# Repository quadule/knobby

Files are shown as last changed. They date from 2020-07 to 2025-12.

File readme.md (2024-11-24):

# Knobby: a little remote for Spotify and more





## Knobby is the remote control made for discovering music and rediscovering your own collection; _your one-click cure for musical boredom_.

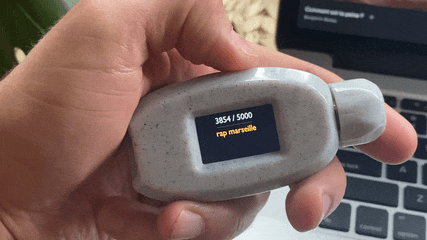
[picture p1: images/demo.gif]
example of playing a random genre with a Knobby


### One knob controls your musical universe

* Spin and explore **6,000+** microgenre and country playlists from [everynoise.com](https://everynoise.com)
* Or hold the knob to randomize — **put all of Spotify on shuffle!**
* Enjoy fast access to your own playlists and liked songs
* See what's playing and control playback on any Spotify Connect device

<br clear="all">
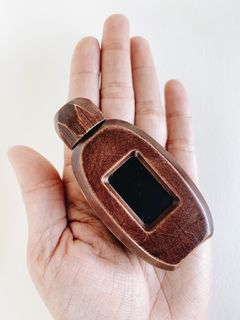
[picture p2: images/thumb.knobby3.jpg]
knobby with wood finish in hand


### Untether music from your phone

Always ready, free from distractions, and designed to be shared: Knobby is the perfect partner to any smart speaker. Show off your meticulously curated collection in your home, or pass it around a party and let your guests take control.

<br clear="all">
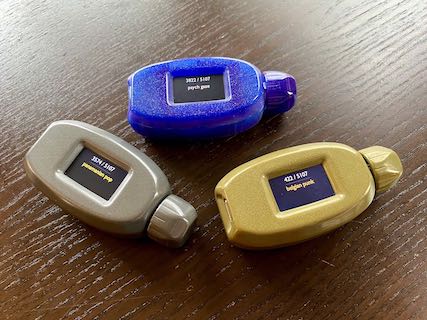
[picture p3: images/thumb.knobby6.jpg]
three knobby remotes


### Make it yours(elf)

Knobby’s minimal design is easy to build and customize, with open source firmware based on the Arduino framework. The 3D printed enclosure is designed around a common ESP32 development board and a single rotary encoder. You can [buy one from me](https://www.tindie.com/products/milowinningham/knobby-a-little-remote-for-spotify-and-more/) to support this project, or [build one yourself](#build-your-own).


<br clear="all">

### See it in action

https://user-images.githubusercontent.com/15299/221440478-d7a543d5-4e82-4146-b03c-dc35ea191b35.mp4

### Read more

- [**Hackaday**: Small Spotify Remote Broadens Musical Horizons](https://hackaday.com/2020/10/21/small-spotify-remote-broadens-musical-horizons/)
- [**Hackster**: Knobby Is a Unique Handheld Remote That Controls Spotify Connect Devices](https://www.hackster.io/news/knobby-is-a-unique-handheld-remote-that-controls-spotify-connect-devices-e3428e100ab6)
- [**Tindie Blog**: Knobby! Explore Music in a New Way](https://blog.tindie.com/2022/11/knobby-explore-music-in-a-new-way/)

## Usage

* Turn the knob to navigate between menu items.
* Click the knob to select or play something.
* Push in and rotate the knob to switch menus.
* Hold the knob for couple seconds for a random genre, country, or playlist from the last open menu.
  - Keep holding the knob until the progress bar reaches the end to play immediately.
  - Release the knob before the progress bar reaches the end to keep browsing.
* When browsing genres, double click the knob to switch between the default alphabetical order and sorting by suffix.
* When playing something, double click the knob to skip to the next track.

### Requirements

* **Spotify Premium** is required — Knobby will not function properly on a free account.
* An always-on playback Spotify Connect device is highly recommended. Knobby can control any Spotify app or device, but a smart speaker or home audio system usually works best. If using a mobile app or some devices such as Chromecast, playback must be started before it can be controlled though Knobby.

## Build your own

### Get the parts

* [LilyGO TTGO T-Display ESP32 board with ST7789 240x135 display](https://www.aliexpress.com/item/33048962331.html)
* [Bourns PEC11R-4215F-S0024 rotary encoder](https://www.mouser.com/ProductDetail/Bourns/PEC11R-4215F-S0024?qs=Zq5ylnUbLm5lAqmKF80wzQ%3D%3D)
* [MakerFocus 1100mAh LiPo battery](https://www.makerfocus.com/products/makerfocus-3-7v-1100mah-lithium-rechargeable-battery-1s-3c-lipo-battery-with-protection-board-pack-of-4)
* [3D printed case and knob](https://www.printables.com/model/156363)

Or, install the firmware on another supported ESP32 development board:

* [LilyGO T-Embed](https://www.lilygo.cc/products/t-embed)

### Wire it up

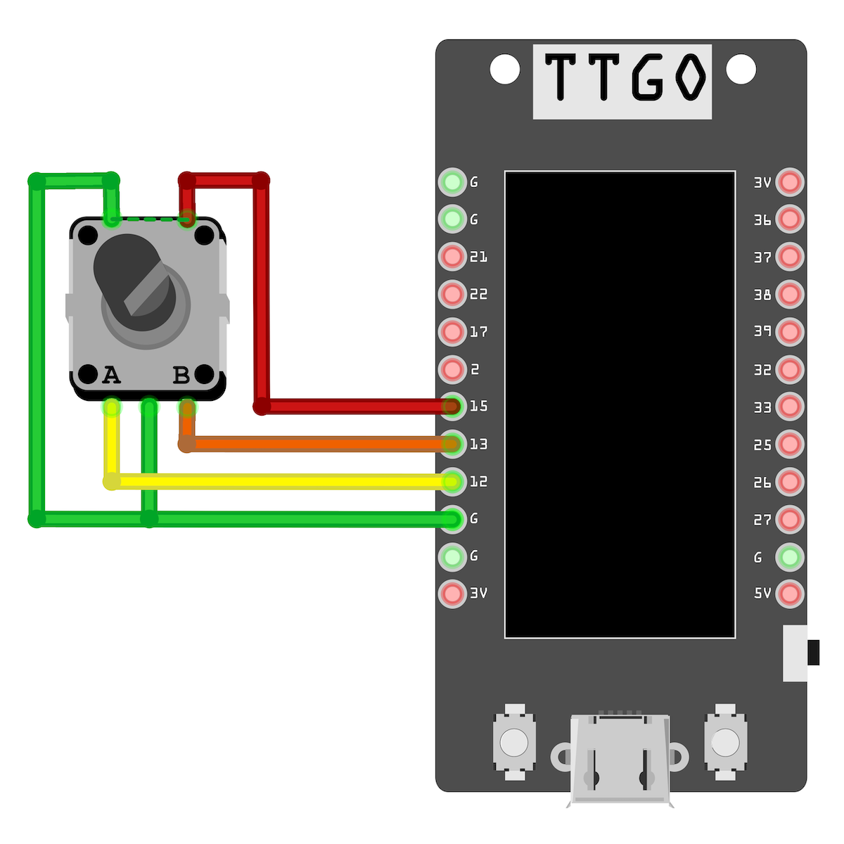
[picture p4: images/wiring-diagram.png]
wiring diagram of rotary encoder with t-display board


1. Connect the rotary encoder A and B pins to GPIO pins 12 and 13.
2. Connect one pole of the switch to GPIO pin 15.
3. Connect other pole of the switch and the encoder’s remaining middle pin to ground.

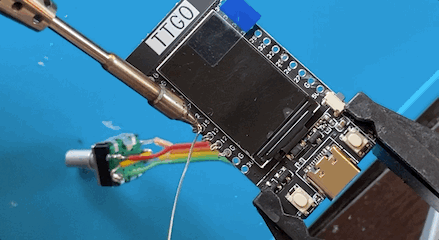
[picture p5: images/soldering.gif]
soldering rotary encoder’s wires to the circuit board


### Install the firmware
#### ➡️ [setup.knobby.net](https://setup.knobby.net)

The [Knobby setup tool](https://setup.knobby.net) can flash the latest firmware and configure wifi credentials over USB (requires Google Chrome or Microsoft Edge for Web Serial API support).

Alternatively, you can download [the latest release](https://github.com/quadule/knobby/releases/latest) and flash it yourself. You will need to have Python and [esptool.py](https://github.com/espressif/esptool) installed. With the USB cable connected, run the flash script in the directory of the extracted firmware zip:

  - on Linux or Mac: `./flash.sh`
  - on Windows: `flash.bat`

### Web configuration

Additional configuration is available at http://knobby.local after knobby is connected to your network. From this page, you can change hardware settings or apply a manual firmware update.

You'll need the device password for this, which is randomly generated on first boot if not configured in `data.json`. You can see the configured password in the serial console output over USB, or by double-clicking the knob on the settings > about screen.

#### Custom builds and other rotary encoders

You may need to adjust the pin assignments or pulse count to work with different hardware. If you find that the knob must be turned two clicks to move one item through the menu, try changing the pulse count from `4` to `2`. The scroll direction can be also reversed by swapping the A and B pins.

These settings can be changed from the web configuration page, or also by editing `data/data.json` when setting up a device for the first time (see below).

### Compile from source

1. Edit `data/data.json` and update the configuration if necessary.
2. Build and upload with [PlatformIO](https://platformio.org/): `pio run && pio run --target upload && pio run --target uploadfs`

If data.json is not configured or there is a problem connecting to your network, knobby will enter configuration mode. Join the temporary wifi network displayed on screen and wait for the configuration portal to appear or visit http://192.168.4.1. Enter your wifi network information, then switch back to your normal wifi network and visit http://knobby.local to continue.

## License

All code is released under the MIT license. The case design is released under the [CC-BY-NC 4.0 license](https://creativecommons.org/licenses/by-nc/4.0/).

## Credits

* Spotify playlists and inspiration from Glenn McDonald's wonderful [Every Noise at Once](https://everynoise.com).
* Icons from [Google Material](https://material.io/resources/icons/) and [Typicons](https://www.s-ings.com/typicons/).

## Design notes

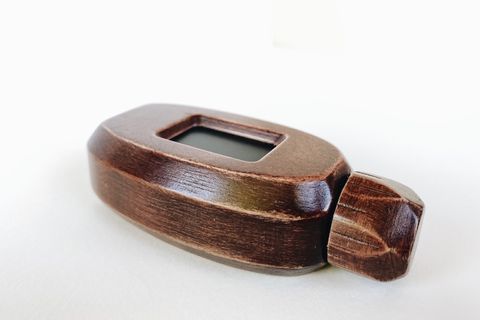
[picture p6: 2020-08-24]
images/thumb.knobby2.jpg

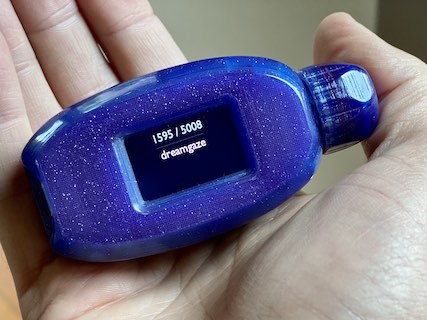
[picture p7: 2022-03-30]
images/thumb.knobby5.jpg

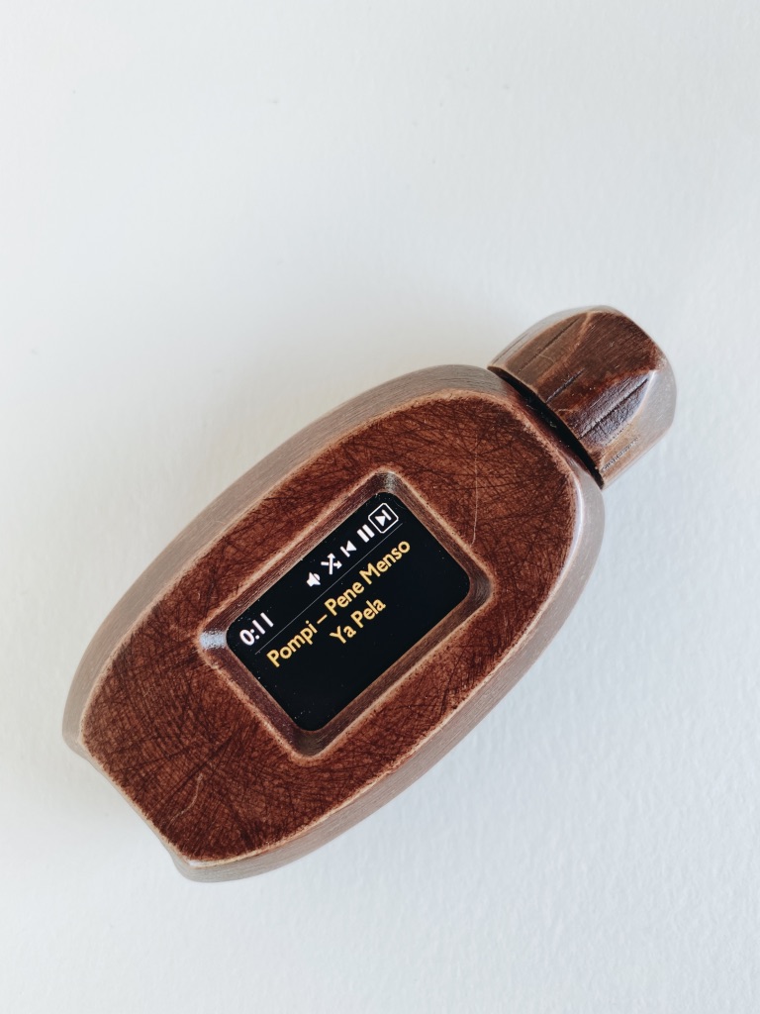
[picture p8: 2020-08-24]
images/knobby4.jpg

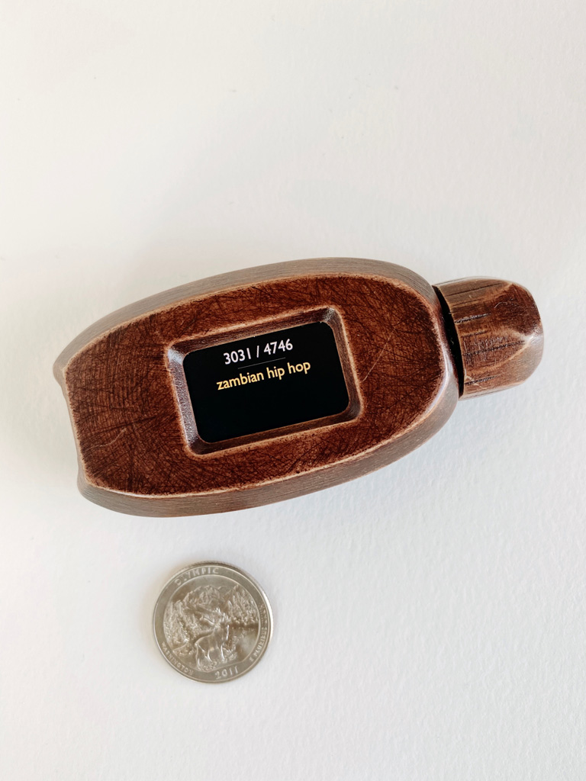
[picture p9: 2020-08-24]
images/knobby1.jpg

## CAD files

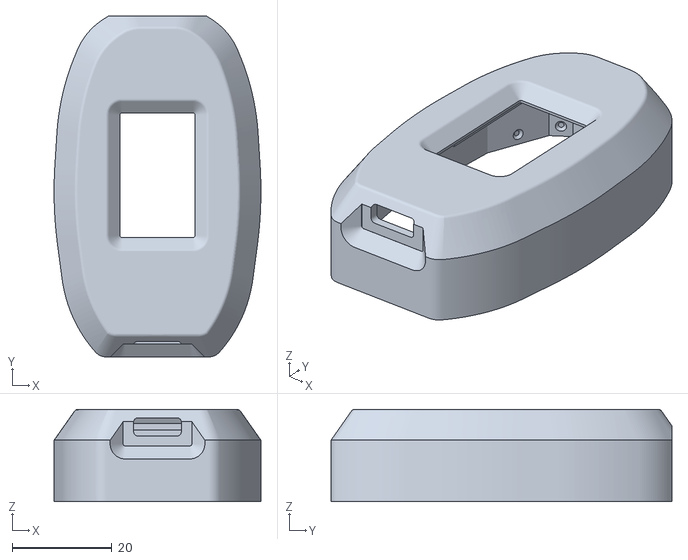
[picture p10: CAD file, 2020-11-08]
case/case-body.stl
41.4 x 68.3 x 18.4

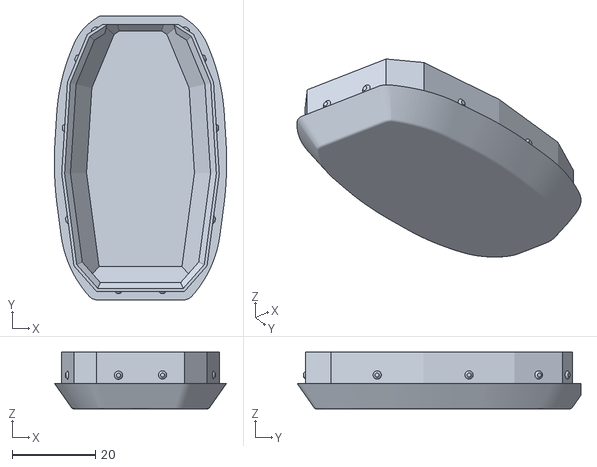
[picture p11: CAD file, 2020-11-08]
case/case-lid.stl
41.4 x 68.3 x 13.7

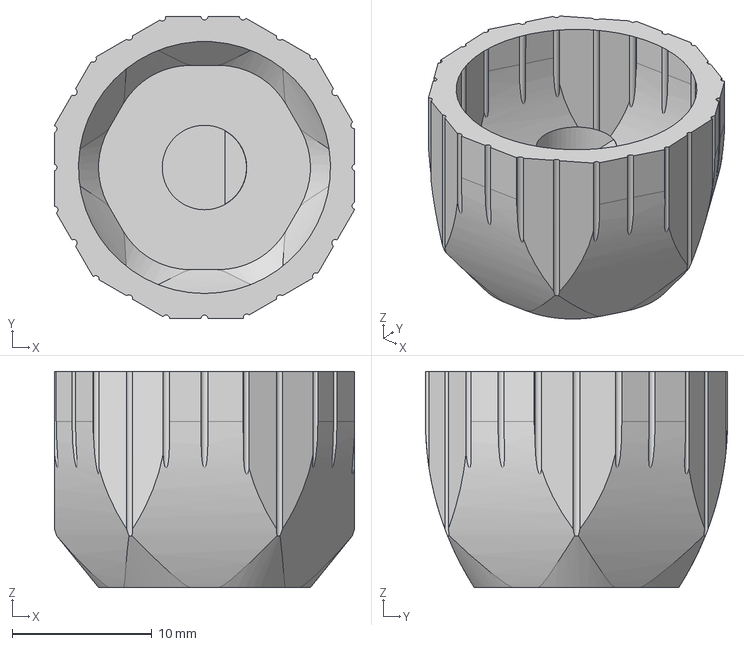
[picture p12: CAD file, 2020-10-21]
case/knob.step
21.5 x 21.7 x 15.5 mm

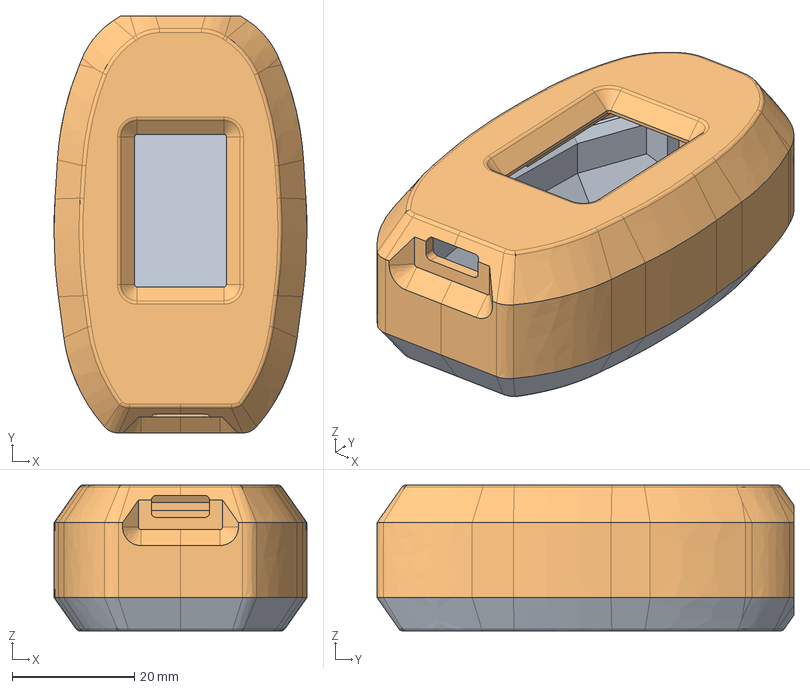
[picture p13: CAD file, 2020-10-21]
case/case.step
41.4 x 68.3 x 23.9 mm
lid

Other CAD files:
case/knob.stl

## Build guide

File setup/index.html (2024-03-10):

# knobby setup

This tool can setup and configure your knobby (https://knobby.net) device via USB. After connecting, you can:

- Install or upgrade the latest knobby firmware
- Set the WiFi network that your knobby connects to
- View logs and reboot with the serial console

To begin, click Connect and select your device from the list. If your knobby is asleep, click the knob to wake it up first.

The tool is not available because your browser does not support Web Serial (https://developer.mozilla.org/en-US/docs/Web/API/Web_Serial_API). Open this page in Google Chrome or Microsoft Edge instead (but not on your iOS device).

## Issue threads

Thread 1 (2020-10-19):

Missing required parameter: client_id

spattinson, 2020-10-19:
When I visit http://knobby.local it redirects to https://accounts.spotify.com/authorize/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 and in the browser the response is **"Missing required parameter: client_id"**

meanwhile in the serial monitor it repeats **"Need access token"**

Maybe the data.json is not building correctly? All it contains is {"users":[]} or does that get populated later?

Thanks for posting this is looks great!

quadule, 2020-10-19:
Thanks for trying it out and reporting this!

I think I ran into this problem before and filed this PR: https://github.com/me-no-dev/ESPAsyncWebServer/pull/834 That redirect URI is overflowing the buffer used for the response so the `client_id` param isn't getting appended. The data.json is correct; it does get populated after authorizing with Spotify.

Until ESPAsyncWebServer is updated, you'll have to apply my patch to your copy of the library in `~/.platformio/lib`. I also plan to release compiled firmware with this fixed after I've done #2 and #3.

spattinson, 2020-10-19:
Thanks for the fast response. That was the issue. I'm seeing the api requests in the serial monitor now.
Now I need to wait for the encoder to arrive.
Not needing a settings file would be cool.
Great work thanks!

quadule, 2020-11-19:
I've changed platformio.ini to use my own fork of ESPAsyncWebServer for now, so this should no longer be an issue.

Closed 2020-11-19.

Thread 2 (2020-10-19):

Switch to PKCE authorization

quadule, 2020-10-19:
This should eliminate the need to compile in the `client_secret` and make it possible to release a firmware binary.

https://developer.spotify.com/documentation/general/guides/authorization-guide/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

quadule, 2020-11-19:
I have this implemented in https://github.com/quadule/knobby/tree/pkce but am not sure if I want to merge it. Spotify's PKCE implementation revokes the old `refresh_token` whenever fetching an `access_token` which complicates things slightly: If a network or device glitch ever prevents the updated `refresh_token` from being saved, the user would have to re-authenticate in a browser. This is also annoying when testing the software because it prevents sharing of tokens between devices.

Closed 2021-02-04.

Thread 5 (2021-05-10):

I'm getting a "Certificate verification failed" error

lmore377, 2021-05-10:
I keep getting this error after I click agree on the spotify page. I get this with the latest release (knobby-1.0-pre) and the latest git commit.

```
[I][ArduinoOTA.cpp:130] begin(): OTA server at: knobby.local:3232
[I][main.cpp:396] loop(): [1638] Connected to wifi with IP address 192.168.1.176
[I][main.cpp:159] operator()(): [11760] server.on /
[I][main.cpp:169] operator()(): [11818] server.on /authorize
[I][main.cpp:1809] spotifyGetToken(): [15457] POST /api/token
[E][ssl_client.cpp:36] _handle_error(): [start_ssl_client():202]: (-9984) X509 - Certificate verification failed, e.g. CRL, CA or signature check failed
[E][WiFiClientSecure.cpp:132] connect(): start_ssl_client: -9984
[W][HTTPClient.cpp:1317] returnError(): error(-1): connection refused
[W][HTTPClient.cpp:1317] returnError(): error(-4): not connected
```

lmore377, 2021-05-11:
I managed to get it to work by copying the cert in spotify,h from [this commit](https://github.com/quadule/knobby/commit/9279bf0c23c715bbc510ea6bf813796843e5db69) to the latest commit.

On an unrelated note, I picked up a generic alps rotary encoder from ebay (they seem to be the most common and readily available) and while it does work, I have to turn the knob 2 ticks to get it to move in either direction. Do you know if there's any way to get it to work? I tried the other attach methods in the ESP32Encoder library but they just make it worse.

quadule, 2021-05-11:
Glad to hear you got it working. Spotify changed their certificate last week but it should be fixed now. I’ve pulled and rereleased `v1.0-pre` a few times so I’m guessing you had an old one. I’ll have a new one pushed shortly.

For the rotary encoder issue, try changing [`ROTARY_ENCODER_PULSE_COUNT` in platformio.ini](https://github.com/quadule/knobby/blob/ab1afc59ccce196b091cbbd77e43242a2168cd33/platformio.ini#L53) to 2. I may move that option to data.json so it won’t require a custom build.

lmore377, 2021-05-11:
It works fine now without any modification and changing the pulse count worked too. Thanks!

quadule, 2021-05-11:
> Liking isn't working but adding user-library-modify to the scopes makes it work.

Thanks for catching that! Looks like it was only working for me while using the same Spotify account that registered the application for their API.

lmore377, 2021-05-12:
I'm having this weird issue where the knobby will go to sleep and won't wake up at all unless I open it and press the reset button or plug it into USB and unplug it (it doesn't have to be plugged in for long at all. Literally less than a second gets it booting) but this only happens on battery. On USB it works perfectly fine and I'm about 90% sure it's not the battery because when it's in this state, the battery still has voltage and when I get it back on it shows that the battery still has a full charge. Do you think my board is faulty or is there something wrong with the code?

lmore377, 2021-05-12:
https://photos.app.goo.gl/YeP6PZLAZp5y48tz5 I just want you to see how weird this is

lmore377, 2021-05-13:
Soooo turns out it was a hardware problem. I have 2 of the esp modules. On the first one the screen was broken but I decided to transfer the screen from the 2nd one to the first one and now it works fine.

quadule, 2021-06-17:
Ok, closing this then. Glad to hear it's working for you now!

Closed 2021-06-17.

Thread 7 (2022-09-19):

Liked songs playlist missing from Playlists?

nullstalgia, 2022-09-19:
Hi! Just wanted to say I love this project and assembled my own earlier today. (I'm surprised you don't have a Tindie or something set up, quite frankly.)

However, as someone who uses the Liked songs playlist (I know it has issues), that's the one thing I'm missing! I hope I'm just not missing something in the UI.

quadule, 2022-09-20:
Hi, I'm glad to hear you're enjoying it! I do hope to get a Tindie shop up sometime.

You are right that there's currently no way to access liked songs. I haven't built any UI for browsing individual tracks yet, and was originally planning to do a larger refactor before attempting that.

Spotify has a separate API for getting saved tracks instead of representing them as a playlist, but I just noticed that they can also be played from a context_uri like `spotify:user:{user_id}:collection`. That should make it easy to add a virtual Liked Songs playlist to the beginning of the Playlists menu, so you could at least start playing and skip between songs from there. I think I can add that to the next release!

nullstalgia, 2022-09-20:
Awesome! Also, I might throw in a PR soon since I think the Double-Tap in Genre menu is bugged (only switching between the first two `GenreSortModes`), but I've been having issues compiling...

I'll throw the errors at you in case you've seen them before:

> Error: Could not find one of 'package.json' manifest files in the package

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

> Unable to determine what CMake generator to use. Please install or configure a preferred generator, or update settings.json, your Kit configuration or PATH variable.

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

Before it was saying "Bad cmake executable" until I installed it from the website, and now I'm getting those errors. PlatformIO is great but I find it annoying sometimes 😅

nullstalgia, 2022-09-20:
Ahh, seems you only added the new options in a recent commit, gotcha.

And I was able to successfully compile on my Linux machine. Didn't try uploading via Serial, but the OTA with the .bin worked for me.

quadule, 2022-11-07:
Just released a [new version](https://github.com/quadule/knobby/releases/tag/2022.11.06) with this added; thanks again for the suggestion!

nullstalgia, 2022-12-24:
Awesome!

But sadly, it's not working for me. When I select that playlist, Spotify just stops playing and the controls grey out on the Desktop.
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

Closed 2022-11-07.

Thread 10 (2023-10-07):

Knobby reboot when using external speaker on Mac Spotify App

pnevin10, 2023-10-07:
Hi, I've noticed that Knobby will reboot when the Spotify app (Mac v1.2.21.1104.g42cf0a50) tries to use an external speaker.  I can start Spotify App and Knobby can control audio.  As soon as I tell the Spotify app to use an external speaker the Knobby will reboot.  This problem does not occur when you use the web-based Spotify application (Chrome tested).

I can reproduce this issue on two Knobby devices with the latest firmware installed.

###### Working just fine with Mac Spotify App using internal laptop speaker
[ 47020][I][main.cpp:2238] spotifyApiRequest(): GET /v1/me/player?market=from_token
[ 57354][I][main.cpp:2238] spotifyApiRequest(): GET /v1/me/player?market=from_token
[ 67803][I][main.cpp:2238] spotifyApiRequest(): GET /v1/me/player?market=from_token
####### Selected external speaker here!
Guru Meditation Error: Core  1 panic'ed (LoadProhibited). Exception was unhandled.

Core  1 register dump:
PC      : 0x40001650  PS      : 0x00060e30  A0      : 0x800dd555  A1      : 0x3ffe2aa0
A2      : 0x50000454  A3      : 0x00000000  A4      : 0x0000003f  A5      : 0x0000ff00
A6      : 0x00ff0000  A7      : 0xff000000  A8      : 0x00000000  A9      : 0x3ffe2a50
A10     : 0x50000454  A11     : 0x000000ff  A12     : 0x00000001  A13     : 0x00000000
A14     : 0x00ff0000  A15     : 0x40404040  SAR     : 0x00000020  EXCCAUSE: 0x0000001c
EXCVADDR: 0x00000000  LBEG    : 0x4000164d  LEND    : 0x40001667  LCOUNT  : 0xffffffff

Backtrace: 0x4000164d:0x3ffe2aa0 0x400dd552:0x3ffe2ab0 0x400dfa80:0x3ffe2c60

ELF file SHA256: 373458490d8a5009

Rebooting...
ets Jul 29 2019 12:21:46

rst:0xc (SW_CPU_RESET),boot:0x13 (SPI_FAST_FLASH_BOOT)
configsip: 0, SPIWP:0xee
clk_drv:0x00,q_drv:0x00,d_drv:0x00,cs0_drv:0x00,hd_drv:0x00,wp_drv:0x00
mode:DIO, clock div:2
load:0x3fff0030,len:3992
load:0x40078000,len:15024
load:0x40080400,len:3648
entry 0x40080600
[  1257][I][ArduinoOTA.cpp:141] begin(): OTA server at: knobby.local:3232

    _                 _     _              |
   | |               | |   | |             |
   | |  _ ____   ___ | |__ | |__  _   _    |   mac C8:C9:A3:FC:08:28
   | |_/ )  _ \ / _ \|  _ \|  _ \| | | |   |   built Jul 20 2023 22:51:53
   |  _ (| | | | |_| | |_) ) |_) ) |_| |   |   git version a281064
   |_| \_)_| |_|\___/|____/|____/ \__  |   |   esp-idf 4.4.4
    by milo winningham           (____/    |   arduino 2.0.10
    https://knobby.net                     |
___________________________________________|____________________________________

E (2726) wifi:Association refused temporarily, comeback time 25 mSec
    setup this device via usb or wifi:
      * (re)connect and visit https://setup.knobby.net to configure

E (2808) wifi:Association refused temporarily, comeback time 25 mSec
E (2837) wifi:Association refused temporarily, comeback time 25 mSec

pnevin10, 2023-10-07:
The Chrome Spotify app does the same thing.

JJSphar, 2023-10-09:
What kind of external speaker are you trying to use?

Specifically, I saw this happen on my Knobby when trying to move playback onto a Sonos speaker. It looks like they are locked down behind the API:
[Sonos speakers not showing in GET /player/devices](https://community.spotify.com/t5/Spotify-for-Developers/Sonos-speakers-not-showing-in-GET-player-devices/m-p/5175469/highlight/true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)

quadule, 2023-10-15:
Hi @pnevin10, I've been looking into this but can't seem to reproduce the problem yet. I also suspect the issue may be related to the external speaker. Could you share the response you get from the [`/v1/me/player` Spotify API](https://developer.spotify.com/documentation/web-api/reference/get-information-about-the-users-current-playback) when playing something on that speaker?

icurnvs, 2023-11-28:
@quadule Hi there - here's the result of my API call.  In my devices list within the knobby menu, I have my two Amazon Echo devices, my PC (spotify app), and 'Everywhere'.  My Sonos speakers do not show up and when I use the Spotify PC app to move playback to a Sonos speaker, the Knobby sort of glitches out and seems to go into a quick boot loop.  If I use the Spotify PC app to return playback to either of the Echos or my PC Spotify app, the knobby exits its boot loop.

In this case, 'Beam' is a Sonos soundbar.
```
{
  "device": {
    "id": null,
    "is_active": true,
    "is_private_session": false,
    "is_restricted": true,
    "name": "Beam",
    "type": "Speaker",
    "volume_percent": 9,
    "supports_volume": true
  },
  "repeat_state": "off",
  "shuffle_state": false,
  "context": {
    "type": "collection",
    "href": "https://api.spotify.com/v1/me/tracks",
    "external_urls": {
      "spotify": "https://open.spotify.com/collection/tracks"
    },
    "uri": "spotify:user:tylerrydell:collection"
  },
  "timestamp": 1701139334404,
  "progress_ms": 245579,
  "is_playing": true,
  "item": {
    "album": {
      "album_type": "album",
      "total_tracks": 13,
      "external_urls": {
        "spotify": "https://open.spotify.com/album/52AeC4gwbxDfFlLHgK1ByD"
      },
      "href": "https://api.spotify.com/v1/albums/52AeC4gwbxDfFlLHgK1ByD",
      "id": "52AeC4gwbxDfFlLHgK1ByD",
      "images": [
        {
          "url": "https://i.scdn.co/image/ab67616d0000b273707d13d3f87652e737e94d45",
          "height": 640,
          "width": 640
        },
        {
          "url": "https://i.scdn.co/image/ab67616d00001e02707d13d3f87652e737e94d45",
          "height": 300,
          "width": 300
        },
        {
          "url": "https://i.scdn.co/image/ab67616d00004851707d13d3f87652e737e94d45",
          "height": 64,
          "width": 64
        }
      ],
      "name": "Urban Hymns (Remastered 2016)",
      "release_date": "1997-09-29",
      "release_date_precision": "day",
      "type": "album",
      "uri": "spotify:album:52AeC4gwbxDfFlLHgK1ByD",
      "artists": [
        {
          "external_urls": {
            "spotify": "https://open.spotify.com/artist/2cGwlqi3k18jFpUyTrsR84"
          },
          "href": "https://api.spotify.com/v1/artists/2cGwlqi3k18jFpUyTrsR84",
          "id": "2cGwlqi3k18jFpUyTrsR84",
          "name": "The Verve",
          "type": "artist",
          "uri": "spotify:artist:2cGwlqi3k18jFpUyTrsR84"
        }
      ],
      "is_playable": true
    },
    "artists": [
      {
        "external_urls": {
          "spotify": "https://open.spotify.com/artist/2cGwlqi3k18jFpUyTrsR84"
        },
        "href": "https://api.spotify.com/v1/artists/2cGwlqi3k18jFpUyTrsR84",
        "id": "2cGwlqi3k18jFpUyTrsR84",
        "name": "The Verve",
        "type": "artist",
        "uri": "spotify:artist:2cGwlqi3k18jFpUyTrsR84"
      }
    ],
    "disc_number": 1,
    "duration_ms": 357266,
    "explicit": false,
    "external_ids": {
      "isrc": "GBUM71601816"
    },
    "external_urls": {
      "spotify": "https://open.spotify.com/track/57iDDD9N9tTWe75x6qhStw"
    },
    "href": "https://api.spotify.com/v1/tracks/57iDDD9N9tTWe75x6qhStw",
    "id": "57iDDD9N9tTWe75x6qhStw",
    "is_playable": true,
    "name": "Bitter Sweet Symphony - Remastered 2016",
    "popularity": 82,
    "preview_url": "https://p.scdn.co/mp3-preview/8b56a0a99ec6675ac20c4c9d69565897e510c491?cid=aea2247cc55a49b1bc6d97895c4b6de9",
    "track_number": 1,
    "type": "track",
    "uri": "spotify:track:57iDDD9N9tTWe75x6qhStw",
    "is_local": false
  },
  "currently_playing_type": "track",
  "actions": {
    "disallows": {
      "resuming": true,
      "skipping_prev": true
    }
  }
}
```

icurnvs, 2023-11-28:
As @JJSphar pointed out, it looks like Sonos speakers aren't returned in the device list.  Is there a way for knobby to handle when playback is occurring on a device not in the devices list?  If it's not feasible to initiate playback on a restricted device, is it perhaps possible for us to start playback on knobby, move playback to a restricted device, and then be able to control that session(skip, play/pause, etc.)?

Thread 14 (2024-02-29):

Knobby Setup Site Issues

nullstalgia, 2024-02-29:
Couldn't find a repo for it, so wanted to note some bugs I had.

1. WiFi Password field is missing, I always have to use "Other Network" to get the prompt.

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

2. Rarely will ask to install Knobby on already-flashed device until after opening Logs and hitting Reset Device.

3. Mesh network duplicates aren't suppressed. Pretty minor.
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

quadule, 2024-03-03:
Thanks for reporting these; I've pushed a few updates to address them:

1. Turns out the "password required" flag in the [improv-wifi](https://github.com/improv-wifi) serial protocol was flipped, but older versions of [esp-web-tools](https://github.com/esphome/esp-web-tools) didn't care and always showed the password field. I'm pinning the older version of esp-web-tools for now to fix this issue for users running older firmware.

2. I've seen this a couple times before — not sure if there's much I can do but I added a note to wake the device first before connecting.

3. This one was easy enough to fix; duplicate SSIDs should be skipped now.

Closed 2024-03-03.

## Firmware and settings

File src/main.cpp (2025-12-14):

#include <ArduinoJson.h>
#include <ArduinoOTA.h>
#include <base64.h>
#include <driver/rtc_io.h>
#include <esp_adc_cal.h>
#include <esp_pm.h>
#include <esp_system.h>
#include <esp_task_wdt.h>
#include <esp_wifi.h>
#include <ESPmDNS.h>
#include <ImprovSerial.h>
#include <mbedtls/md.h>
#include <SPIFFS.h>
#include <StreamString.h>
#include <time.h>
#include <wifi_provisioning/manager.h>

#include "main.h"
#include "genres.h"

void setup() {
  spotifyImage.reserve(8192);
  exploreMenuItems.reserve(20);
  spotifyDevices.reserve(10);
  spotifyUsers.reserve(10);
  spotifyLinkedPlaylists.reserve(10);
  spotifyPlaylists.reserve(200);

  #ifdef POWER_ON_PIN
    pinMode(POWER_ON_PIN, OUTPUT);
    digitalWrite(POWER_ON_PIN, HIGH);
  #endif

  #ifdef CONFIG_IDF_TARGET_ESP32S3
    Serial.begin();
  #else
    Serial.begin(115200);
  #endif

  knobby.setup();
  rtc_gpio_hold_dis((gpio_num_t)ROTARY_ENCODER_BUTTON_PIN);
  setLightSleepEnabled(true);
  ESP_ERROR_CHECK(esp_wifi_set_ps(WIFI_PS_MAX_MODEM));

  #ifdef LILYGO_WATCH_2019_WITH_TOUCH
    ttgo = TTGOClass::getWatch();
    ttgo->setTftExternal(tft);
    ttgo->begin();
    ttgo->openBL();
    ttgo->setBrightness(255);

    // Turn on the IRQ used
    ttgo->power->adc1Enable(AXP202_BATT_VOL_ADC1 | AXP202_BATT_CUR_ADC1 | AXP202_VBUS_VOL_ADC1 | AXP202_VBUS_CUR_ADC1, AXP202_ON);
    ttgo->power->enableIRQ(AXP202_VBUS_REMOVED_IRQ | AXP202_VBUS_CONNECT_IRQ | AXP202_CHARGING_FINISHED_IRQ, AXP202_ON);
    ttgo->power->clearIRQ();

    // Turn off unused power
    ttgo->power->setPowerOutPut(AXP202_EXTEN, AXP202_OFF);
    ttgo->power->setPowerOutPut(AXP202_DCDC2, AXP202_OFF);
    ttgo->power->setPowerOutPut(AXP202_LDO3, AXP202_OFF);
    ttgo->power->setPowerOutPut(AXP202_LDO4, AXP202_OFF);
  #else
    ledcSetup(backlightChannel, 12000, 8);
    ledcAttachPin(TFT_BL, backlightChannel);
    ledcWrite(backlightChannel, 255);
    tft.init();
    tft.fillScreen(TFT_BLACK);
  #endif

  SPIFFS.begin(true);
  readDataJson();
  WiFi.setHostname(hostname);
  WiFi.begin();
  improvSerial.setup(hostname);

  setupKnob();

  tft.setRotation(knobby.flippedDisplay() ? 1 : 3);
  tft.loadFont(GillSans24_vlw_start);
  img.loadFont(GillSans24_vlw_start);
  ico.loadFont(icomoon24_vlw_start);
  batterySprite.loadFont(icomoon31_vlw_start);

  TJpgDec.setJpgScale(1);
  TJpgDec.setSwapBytes(true);
  TJpgDec.setCallback(onJpgBlockDecoded);

  if (bootCount == 0) {
    log_d("Boot #%d", bootCount);
    countryIndex = random(COUNTRY_COUNT);
    genreIndex = random(GENRE_COUNT);
  } else {
    struct timeval tod;
    gettimeofday(&tod, NULL);
    time_t currentSeconds = tod.tv_sec;
    secondsAsleep = currentSeconds - lastSleepSeconds;
    log_d("Boot #%d, asleep for %ld seconds", bootCount, secondsAsleep);
    uint32_t millisPassed = secondsAsleep * 1000 + millis();
    if (secondsAsleep > newSessionSeconds ||
        (spotifyState.isPlaying && (spotifyState.estimatedProgressMillis + millisPassed > spotifyState.durationMillis))) {
      spotifyState.isShuffled = false;
      spotifyState.repeatMode = RepeatOff;
      spotifyResetProgress();
      spotifyStateLoaded = false;
    } else if (spotifyState.isPlaying) {
      spotifyState.imageUrl[0] = '\0';
      spotifyState.progressMillis = spotifyState.estimatedProgressMillis =
          spotifyState.estimatedProgressMillis + millisPassed;
    }
  }
  bootCount++;

  wifi_prov_mgr_config_t config;
  ESP_ERROR_CHECK(wifi_prov_mgr_init(config));

  bool wifiProvisioned = false;
  ESP_ERROR_CHECK(wifi_prov_mgr_is_provisioned(&wifiProvisioned));
  wifiConnectWarning = !wifiProvisioned;

  if (wifiConnectWarning || spotifyUsers.empty()) {
    setMenuMode(InitialSetup, 0);
    menuSize = 0;
    tft.fillScreen(TFT_BLACK);
    drawMenuHeader(true, "setup knobby");
    if (wifiConnectWarning) startWifiManager();
  } else {
    if (secondsAsleep > newSessionSeconds) {
      genreSort = AlphabeticSort;
      setMenuMode(GenreList, getMenuIndexForGenreIndex(genreIndex));
    }
    knobHeldForRandom = digitalRead(ROTARY_ENCODER_BUTTON_PIN) == LOW;
    if (knobHeldForRandom) {
      startRandomizingMenu(true);
    } else {
      nextCurrentlyPlayingMillis = 1;
    }
  }

  Update.onProgress(onOTAProgress);
  ArduinoOTA.setHostname(hostname);
  ArduinoOTA.setMdnsEnabled(false);
  ArduinoOTA.setPassword(knobby.password().c_str());
  ArduinoOTA.setTimeout(10000);
  ArduinoOTA.onStart([]() {
      int cmd = ArduinoOTA.getCommand();
      if (cmd == U_FLASH) {
        log_i("OTA: updating firmware");
      } else if (cmd == U_SPIFFS) {
        log_i("OTA: updating SPIFFS");
        SPIFFS.end();
      } else {
        log_e("OTA: unknown command %d", cmd);
      }
    })
    .onEnd([]() {
      log_i("OTA: update complete");
      lastInputMillis = millis();
    })
    .onError([](ota_error_t error) {
      log_e("OTA: error code %u", error);
      setStatusMessage("update failed");
    });
  ArduinoOTA.begin();

  // Initialize HTTP server handlers
  server.on("/", HTTP_GET, [](AsyncWebServerRequest *request) {
    inactivityMillis = 1000 * 60 * 3;
    log_i("server.on /");
    if (spotifyUsers.empty() || (menuMode == SettingsMenu && menuIndex == SettingsAddUser)) {
      request->redirect("http://knobby.local/authorize");
    } else {
      String html;
      html.reserve(4096);
      html.concat(index_html_start);
      html.replace("{{firmwareURL}}", firmwareURL == defaultFirmwareURL ? "" : firmwareURL);
      html.replace("{{flipDisplaySelected}}", knobby.flippedDisplay() ? " selected" : "");
      html.replace("{{rotaryAPin}}", String(knobby.rotaryAPin()));
      html.replace("{{rotaryBPin}}", String(knobby.rotaryBPin()));
      html.replace("{{buttonPin}}", String(knobby.buttonPin()));
      html.replace("{{pulseCount}}", String(knobby.pulseCount()));
      request->send(200, "text/html", html);
    }
  });

  server.on("/authorize", HTTP_GET, [](AsyncWebServerRequest *request) {
    log_i("server.on /authorize");
    spotifyGettingToken = true;

    unsigned char verifier[32];
    for (auto i=0; i<32; i++) verifier[i] = random(256);
    String encoded = base64::encode((const uint8_t *)&verifier, 32);
    encoded.replace('+', '-');
    encoded.replace('/', '_');
    strncpy(spotifyCodeVerifier, encoded.c_str(), 43);

    unsigned char codeVerifierSha[32];
    mbedtls_md_context_t ctx;
    mbedtls_md_init(&ctx);
    mbedtls_md_setup(&ctx, mbedtls_md_info_from_type(MBEDTLS_MD_SHA256), 0);
    mbedtls_md_starts(&ctx);
    mbedtls_md_update(&ctx, (const unsigned char *)&spotifyCodeVerifier, 43);
    mbedtls_md_finish(&ctx, codeVerifierSha);

    encoded = base64::encode(codeVerifierSha, sizeof(codeVerifierSha));
    encoded.replace('+', '-');
    encoded.replace('/', '_');
    strncpy(spotifyCodeChallenge, encoded.c_str(), 43);

    String authUrl;
    authUrl.reserve(500);
    authUrl.concat(
        "https://accounts.spotify.com/authorize/?response_type=code&scope="
        "user-read-private+user-read-currently-playing+user-read-playback-state+"
        "user-modify-playback-state+playlist-read-private+"
        "user-library-read+user-library-modify+user-follow-read+user-follow-modify"
        "&code_challenge_method=S256&code_challenge=");
    authUrl.concat(spotifyCodeChallenge);
    authUrl.concat("&show_dialog=true&redirect_uri=https%3A%2F%2Fsetup.knobby.net%2Fcallback.html&client_id=");
    authUrl.concat(spotifyClientId);
    request->redirect(authUrl);
  });

  server.on("/callback", HTTP_GET, [](AsyncWebServerRequest *request) {
    spotifyAuthCode = "";
    uint8_t paramsNr = request->params();
    for (uint8_t i = 0; i < paramsNr; i++) {
      AsyncWebParameter *p = request->getParam(i);
      if (p->name() == "code") {
        spotifyAuthCode = p->value();
        spotifyGettingToken = true;
        spotifyQueueAction(GetToken);
        break;
      }
    }
    if (spotifyActionIsQueued(GetToken)) {
      setStatusMessage("connecting...");
      request->send(200, "text/plain",
                    "Authorized! Knobby should be ready to use in a moment. You can close this page now.");
    } else {
      request->send(204);
    }
  });

  server.on("/heap", HTTP_GET,
            [](AsyncWebServerRequest *request) { request->send(200, "text/plain", String(ESP.getFreeHeap())); });

  server.on("/sleep", HTTP_GET, [](AsyncWebServerRequest *request) {
    AsyncWebParameter *passwordParam = request->getParam("pass");
    if (!passwordParam || passwordParam->value() != knobby.password()) {
      request->send(403, "text/plain", "Incorrect password");
    } else {
      request->send(200, "text/plain", "OK, sleeping");
      delay(100);
      startDeepSleep();
    }
  });

  server.on("/update", HTTP_POST,
    [](AsyncWebServerRequest *request) {
      AsyncWebParameter *passwordParam = request->getParam("pass", true);
      if (!passwordParam || passwordParam->value() != knobby.password()) {
        request->send(403, "text/plain", "Incorrect password");
      } else {
        bool changed = false;
        AsyncWebParameter *flippedParam = request->getParam("flipDisplay", true);
        if (flippedParam) {
          bool flip = flippedParam->value() == "1";
          if (knobby.flippedDisplay() != flip) {
            knobby.setFlippedDisplay(flip);
            tft.setRotation(knobby.flippedDisplay() ? 1 : 3);
            tft.fillScreen(TFT_BLACK);
            invalidateDisplay(true);
            changed = true;
          }
        }
        AsyncWebParameter *aParam = request->getParam("rotaryAPin", true);
        if (aParam && knobby.rotaryAPin() != aParam->value().toInt()) {
          knobby.setRotaryAPin(aParam->value().toInt());
          changed = true;
        }
        AsyncWebParameter *bParam = request->getParam("rotaryBPin", true);
        if (bParam && knobby.rotaryBPin() != bParam->value().toInt()) {
          knobby.setRotaryBPin(bParam->value().toInt());
          changed = true;
        }
        AsyncWebParameter *buttonParam = request->getParam("buttonPin", true);
        if (buttonParam && knobby.buttonPin() != buttonParam->value().toInt()) {
          knobby.setButtonPin(buttonParam->value().toInt());
          changed = true;
        }
        AsyncWebParameter *pulseCountParam = request->getParam("pulseCount", true);
        if (pulseCountParam && knobby.pulseCount() != pulseCountParam->value().toInt()) {
          knobby.setPulseCount(pulseCountParam->value().toInt());
          changed = true;
        }
        AsyncWebParameter *firmwareParam = request->getParam("firmwareURL", true);
        if (firmwareParam && !firmwareParam->value().isEmpty() && firmwareURL != firmwareParam->value()) {
          firmwareURL = firmwareParam->value();
          startFirmwareUpdateFromURL = true;
          checkedForUpdateMillis = 0;
          changed = true;
        }
        if (changed) {
          writeDataJson();
          if (!startFirmwareUpdateFromURL) setupKnob();
        }
        request->send(200, "text/plain", "OK, changes saved");
      }
    },
    [](AsyncWebServerRequest *request, const String& filename, size_t index, uint8_t *data, size_t len, bool final) {
      AsyncWebParameter *passwordParam = request->getParam("pass", true);
      if (!passwordParam || passwordParam->value() != knobby.password()) {
        request->send(403, "text/plain", "Incorrect password");
        return;
      }

      if (!index){
        updateContentLength = request->contentLength();
        int cmd = (filename.indexOf("spiffs") > -1) ? U_SPIFFS : U_FLASH;
        if (cmd == U_SPIFFS) SPIFFS.end();
        if (!Update.begin(updateContentLength > 0 ? updateContentLength : UPDATE_SIZE_UNKNOWN, cmd)) {
          Update.printError(Serial);
        }
      }

      if (Update.write(data, len) != len) {
        Update.printError(Serial);
      }

      if (final) {
        AsyncWebServerResponse *response = request->beginResponse(302, "text/plain", "Rebooting, please wait...");
        response->addHeader("Refresh", "10");
        response->addHeader("Location", "/");
        request->send(response);
        if (!Update.end(true)){
          updateContentLength = 0;
          Update.printError(Serial);
          setStatusMessage("update failed");
        } else {
          log_i("OTA: update complete");
          Serial.flush();
          delay(100);
          tft.fillScreen(TFT_BLACK);
          ESP.restart();
        }
      }
    }
  );

  server.onNotFound([](AsyncWebServerRequest *request) {
    request->send(404, "text/plain", "404 Not Found");
  });

  server.begin();

  spotifyWifiClient.setCACertBundle(x509_crt_bundle_start);
  spotifyHttp.setUserAgent("Knobby/1.0");
  spotifyHttp.setConnectTimeout(4000);
  spotifyHttp.setTimeout(4000);

  if (spotifyNeedsNewAccessToken()) {
    spotifyGettingToken = true;
    spotifyActionQueue.push_front(GetToken);
  }

  xTaskCreatePinnedToCore(backgroundApiLoop, "backgroundApi", 10000, NULL, 1, &backgroundApiTask, 1);
  xTaskCreatePinnedToCore(jpgDecodeLoop, "jpgDecode", 10000, NULL, 0, &jpgDecodeTask, 0);

  if (knobby.powerStatus() != PowerStatusPowered) knobby.updateBattery();
  if (knobby.powerStatus() == PowerStatusPowered) knobby.printHeader(wifiProvisioned);
}

void setLightSleepEnabled(bool enabled) {
#ifdef CONFIG_IDF_TARGET_ESP32S3
  esp_sleep_pd_config(ESP_PD_DOMAIN_RTC_PERIPH, enabled ? ESP_PD_OPTION_ON : ESP_PD_OPTION_OFF);
  esp_pm_config_esp32s3_t pm_config_ls_enable = {
    .max_freq_mhz = CONFIG_ESP32S3_DEFAULT_CPU_FREQ_MHZ,
    .min_freq_mhz = CONFIG_ESP32S3_DEFAULT_CPU_FREQ_MHZ,
    .light_sleep_enable = enabled
  };
#else
  esp_pm_config_esp32_t pm_config_ls_enable = {
    .max_freq_mhz = CONFIG_ESP32_DEFAULT_CPU_FREQ_MHZ,
    .min_freq_mhz = CONFIG_ESP32_DEFAULT_CPU_FREQ_MHZ,
    .light_sleep_enable = enabled
  };
#endif
  ESP_ERROR_CHECK(esp_pm_configure(&pm_config_ls_enable));
}

void setupKnob() {
  ESP32Encoder::useInternalWeakPullResistors = UP;
  knob = ESP32Encoder();
  knob.attachFullQuad(knobby.rotaryAPin(), knobby.rotaryBPin());
  button = OneButton(knobby.buttonPin(), true, true);
  button.setDebounceTicks(debounceMillis);
  button.setClickTicks(doubleClickMaxMillis);
  button.setPressTicks(longPressMillis);
  button.attachClick(knobClicked);
  button.attachDoubleClick(knobDoubleClicked);
  button.attachLongPressStart(knobLongPressStarted);
  button.attachLongPressStop(knobLongPressStopped);
  button.attachPressStart(knobPressStarted);
}

void startWifiManager() {
  if (wifiManager) return;
  if (knobby.powerStatus() == PowerStatusPowered) {
    inactivityMillis = 1000 * 60 * 10;
  } else {
    inactivityMillis = 1000 * 60 * 5;
  }
  wifiManager = new ESPAsync_WiFiManager(&server, &dnsServer, hostname);
  wifiManager->setBreakAfterConfig(true);
  wifiManager->startConfigPortalModeless(knobby.name().c_str(), knobby.password().c_str(), false);
  dnsServer.setErrorReplyCode(AsyncDNSReplyCode::NoError);
  dnsServer.start(53, "*", WiFi.softAPIP());
}

bool isIdle() {
  return millis() - lastInputMillis > 5000;
}

void delayIfIdle() {
  auto now = millis();
  if (!displayInvalidated && knobby.powerStatus() == PowerStatusOnBattery &&
      (isIdle() || now - lastDelayMillis > 2000)) {
    delay(1);
    lastDelayMillis = now;
  } else if (randomizingMenuEndMillis == 0 && updateContentLength == 0) {
    delay(1);
  }
}

void loop() {
  uint32_t now = millis();
  unsigned long previousInputDelta = (now == lastInputMillis) ? 1 : now - lastInputMillis;
  if (knob.getCount() != lastKnobCount) knobRotated();
  button.tick();
  knobby.loop();
  shutdownIfLowBattery();

  now = millis();
  unsigned long inputDelta = (now == lastInputMillis) ? 1 : now - lastInputMillis;
  bool connected = WiFi.isConnected();

  if ((wifiConnectWarning || spotifyRefreshToken[0] == '\0') && menuMode != InitialSetup && inputDelta > menuTimeoutMillis) {
    setMenuMode(InitialSetup, 0);
  } else if (inputDelta < previousInputDelta && previousInputDelta > inactivityMillis) {
    if (menuMode == NowPlaying && now - spotifyState.lastUpdateMillis > 5000) {
      nextCurrentlyPlayingMillis = 1;
    }
    #ifdef LILYGO_WATCH_2019_WITH_TOUCH
      ttgo->bl->begin();
      ttgo->bl->adjust(255);
    #else
      ledcDetachPin(TFT_BL);
      digitalWrite(TFT_BL, HIGH);
      setLightSleepEnabled(true);
    #endif
  } else if (inputDelta > inactivityMillis + 2 * inactivityFadeOutMillis) {
    startDeepSleep();
  } else if (inputDelta > inactivityMillis) {
    double fadeProgress = 1.0 - (inputDelta - inactivityMillis) / (double)inactivityFadeOutMillis;
    #ifdef LILYGO_WATCH_2019_WITH_TOUCH
      const int minimumDuty = 99;
    #else
      const int minimumDuty = 5;
    #endif
    uint32_t duty = min(max((int)round(fadeProgress * 255.0), minimumDuty), 255);
    if (duty >= 250) {
      setLightSleepEnabled(false);
    }
    #ifdef LILYGO_WATCH_2019_WITH_TOUCH
      ttgo->setBrightness(duty);
    #else
      if (duty >= 250) ledcAttachPin(TFT_BL, backlightChannel);
      ledcWrite(backlightChannel, duty);
    #endif
  } else if (menuMode == VolumeControl && inputDelta > menuTimeoutMillis) {
    setMenuMode(NowPlaying, VolumeButton);
    if (nextCurrentlyPlayingMillis == 0) nextCurrentlyPlayingMillis = 1;
  }

  if (connected && (lastConnectedMillis < 0 || lastReconnectAttemptMillis > lastConnectedMillis)) {
    if (lastConnectedMillis >= 0) {
      setStatusMessage("reconnected");
    } else {
      wifiManager = nullptr;
      WiFi.softAPdisconnect();
      WiFi.mode(WIFI_STA);
      WiFi.setHostname(hostname);
      MDNS.begin(hostname);
      MDNS.addService("http", "tcp", 80);
      setStatusMessage("", 0);
    }
    lastConnectedMillis = now;
    wifiConnectWarning = false;
    if (spotifyUsers.empty() || spotifyRefreshToken[0] == '\0') {
      setMenuMode(InitialSetup, 0);
      invalidateDisplay(true);
    }
    log_i("Connected to wifi with IP address %s", WiFi.localIP().toString().c_str());

    wifi_config_t current_conf;
    esp_wifi_get_config(WIFI_IF_STA, &current_conf);
    current_conf.sta.listen_interval = 5;
    esp_wifi_set_config(WIFI_IF_STA, &current_conf);
  } else if (!connected && !WiFi.SSID().isEmpty() && now - lastReconnectAttemptMillis > wifiConnectTimeoutMillis) {
    lastReconnectAttemptMillis = now;
    if (lastConnectedMillis < 0) {
      if (now > 5000) setStatusMessage("connecting to wifi");
      if (!wifiConnectWarning && now >= wifiConnectTimeoutMillis) {
        log_w("No wifi after %d seconds, starting config portal.", (int)wifiConnectTimeoutMillis / 1000);
        drawSetup();
        setMenuMode(InitialSetup, 0);
        wifiConnectWarning = true;
        startWifiManager();
      }
    }
  }

  now = millis();

  if (menuMode == InitialSetup && !spotifyUsers.empty() && !wifiConnectWarning) {
    setMenuMode(GenreList, 0);
    startRandomizingMenu(false);
  } else if (!knobHeldForRandom && shouldShowRandom() && getExtraLongPressedMillis() > extraLongPressMillis) {
    knobHeldForRandom = true;
    longPressStartedMillis = 0;
    startRandomizingMenu(true);
  }

  if (randomizingMenuEndMillis > 0 && now >= randomizingMenuEndMillis) {
    randomizingMenuEndMillis = 0;
    randomizingMenuNextMillis = 0;
    if (randomizingMenuAutoplay) {
      spotifyActionQueue.clear();
      playMenuPlaylist(lastPlaylistMenuMode, menuIndex);
      nowPlayingDisplayMillis = 0;
    } else {
      invalidateDisplay();
    }
  }

  if (spotifyState.isPlaying && now > spotifyState.lastUpdateMillis) {
    spotifyState.estimatedProgressMillis =
        min(spotifyState.durationMillis, spotifyState.progressMillis + (now - spotifyState.lastUpdateMillis));
  }

  if (statusMessageUntilMillis > 0 && now >= statusMessageUntilMillis) {
    statusMessageUntilMillis = 0;
    statusMessage[0] = '\0';
    tft.fillRect(0, 1, screenWidth, 31, TFT_BLACK);
    showingStatusMessage = false;
    invalidateDisplay();
  } else if (clickEffectEndMillis > 0 && now > clickEffectEndMillis) {
    clickEffectEndMillis = 0;
    invalidateDisplay();
  } else if ((randomizingMenuNextMillis > 0 && now >= randomizingMenuNextMillis) ||
              lastInputMillis > lastDisplayMillis || (now - lastDisplayMillis > extraLongPressMillis) ||
              (shouldShowRandom() && lastDisplayMillis < longPressStartedMillis + extraLongPressMillis * 2)) {
    invalidateDisplay();
  }

  if (displayInvalidated && updateContentLength == 0) updateDisplay();

  auto top = menuMode == NowPlaying ? lineDivider : 0;
  if (shouldShowProgressBar()) {
    unsigned long margin = menuMode == NowPlaying ? 4 : 0;
    unsigned long maxWidth = tft.width() - margin * 2;
    unsigned long width = 59;
    unsigned long t = millis() / 2;
    showingProgressBar = true;
    for (unsigned long segment = 0; segment < 4; segment++) {
      unsigned long x = max(margin, maxWidth - (t + width * segment) % maxWidth);
      if (x + width > maxWidth) width -= (x + width) - maxWidth;
      tft.drawFastHLine(x, top, width, segment % 2 == 0 ? TFT_DARKERGREY : TFT_DARKGREY);
    }
  } else if (showingProgressBar) {
    tft.drawFastHLine(0, top, tft.width(), TFT_BLACK);
    showingProgressBar = false;
    updateDisplay();
  }

  ArduinoOTA.handle();
  improvSerial.loop();
  if (wifiManager) wifiManager->loop();
  if (startFirmwareUpdateFromURL) {
    startFirmwareUpdateFromURL = false;
    updateFirmware();
  }
  delayIfIdle();
}
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

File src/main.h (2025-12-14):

#include "sdkconfig.h"
#include <Arduino.h>

#include <ESP32Encoder.h>
#include <ESPAsync_WiFiManager.h>
#include <ESPAsyncDNSServer.h>
#include <ESPAsyncWebServer.h>
#include <HardwareSerial.h>
#include <HTTPClient.h>
#include <list>
#include <OneButton.h>
#include <TFT_eSPI.h>
#include <TJpg_Decoder.h>
#include <WiFiClientSecure.h>

#include "knobby.h"

extern const uint8_t GillSans24_vlw_start[] asm("_binary_GillSans24_vlw_start");
extern const uint8_t icomoon24_vlw_start[] asm("_binary_icomoon24_vlw_start");
extern const uint8_t icomoon31_vlw_start[] asm("_binary_icomoon31_vlw_start");
extern const uint8_t x509_crt_bundle_start[] asm("_binary_x509_crt_bundle_start");
extern const char index_html_start[] asm("_binary_index_html_start");

#define ICON_SIZE 24
#define LINE_HEIGHT 27
#define TFT_LIGHTBLACK 0x1082 /*  16,  16,  16 */
#define TFT_DARKERGREY 0x4A49 /*  72,  72,  72 */
#define SPOTIFY_ID_SIZE 22
#define SPOTIFY_WAIT_MILLIS 1000

enum MenuModes {
  InitialSetup = -99,
  SeekControl = -3,
  VolumeControl = -2,
  RootMenu = -1,
  SettingsMenu = 0,
  CountryList = 1,
  GenreList = 2,
  ExploreList = 3,
  PlaylistList = 4,
  NowPlaying = 5,
  UserList = 6,
  DeviceList = 7
};
enum GenreSortModes {
  AlphabeticSort = 0,
  AlphabeticSuffixSort = 1
};
const int genreSortModesCount = 2;
enum NowPlayingItems {
  LikeButton = 0,
  ShuffleButton = 1,
  BackButton = 2,
  PlayPauseButton = 3,
  NextButton = 4,
  RepeatButton = 5,
  VolumeButton = 6,
  SeekButton = 7
};
enum SettingsMenuModes {
  SettingsAbout = 0,
  SettingsUpdate = 1,
  SettingsOrientation = 2,
  SettingsAddUser = 3,
  SettingsRemoveUser = 4,
  SettingsReset = 5
};

enum GrantTypes { gt_authorization_code, gt_refresh_token };

enum SpotifyActions {
  Idle,
  GetToken,
  CurrentlyPlaying,
  CurrentProfile,
  Next,
  Previous,
  Seek,
  Toggle,
  PlayPlaylist,
  GetDevices,
  SetVolume,
  CheckLike,
  ToggleLike,
  ToggleShuffle,
  ToggleRepeat,
  TransferPlayback,
  GetPlaylistInformation,
  GetPlaylists,
  GetImage
};

enum SpotifyRepeatModes {
  RepeatOff = 0,
  RepeatTrack = 1,
  RepeatContext = 2
};

enum ExploreItemTypes { ExploreItemAlbum, ExploreItemArtist, ExploreItemPlaylist };

typedef struct {
  ExploreItemTypes type;
  char id[SPOTIFY_ID_SIZE + 1] = "";
  String name;
} ExploreItem_t;

typedef struct {
  char displayName[64] = "";
  char id[64]           = "";
  char refreshToken[150] = "";
  bool selected = false;
  char selectedDeviceId[64] = "";
} SpotifyUser_t;

typedef struct {
  char id[64] = "";
  char name[64] = "";
  uint8_t volumePercent;
} SpotifyDevice_t;

typedef struct {
  char id[SPOTIFY_ID_SIZE + 1] = "";
  String name;
} SpotifyPlaylist_t;

typedef struct {
  char id[SPOTIFY_ID_SIZE + 1] = "";
  char name[100] = "";
} SpotifyArtist_t;

typedef struct {
  char name[100] = "";
  SpotifyArtist_t artists[3] = {};
  char artistsName[100] = "";
  char albumName[100] = "";
  char albumId[SPOTIFY_ID_SIZE + 1] = "";
  char trackId[SPOTIFY_ID_SIZE + 1] = "";
  char contextName[256] = "";
  char contextUri[100] = "";
  char imageUrl[100] = "";
  bool isLiked = false;
  bool isPlaying = false;
  bool isShuffled = false;
  SpotifyRepeatModes repeatMode = RepeatOff;
  bool checkedLike = false;
  bool disallowsSkippingNext = true;
  bool disallowsSkippingPrev = true;
  bool disallowsTogglingShuffle = true;
  bool disallowsTogglingRepeatContext = true;
  bool disallowsTogglingRepeatTrack = true;
  bool isPrivateSession = false;
  uint32_t progressMillis = 0;
  uint32_t durationMillis = 0;
  uint32_t estimatedProgressMillis = 0;
  uint32_t lastUpdateMillis = 0;
} SpotifyState_t;

template<typename C, typename T>
bool contains(C&& c, T e) {
  return std::find(std::begin(c), std::end(c), e) != std::end(c);
};
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

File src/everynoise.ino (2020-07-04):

#include "ArduinoJson.h"
#include "ESPAsyncWebServer.h"
#include "ESPRotary.h"
#include "ESPmDNS.h"
#include "OneButton.h"
#include "SPIFFS.h"
#include "StreamString.h"
#include "TFT_eSPI.h"
#include "WiFiClientSecure.h"
#include "base64.h"
#include "driver/rtc_io.h"
#include "esp_adc_cal.h"
#include "time.h"

#define FONT_NAME "GillSans24"
#define ICON_SIZE 24
#define LINE_HEIGHT 27

 const String ICON_VOLUME_UP = "\uE900";
 const String ICON_VOLUME_OFF = "\uE901";
 const String ICON_VOLUME_MUTE = "\uE902";
 const String ICON_VOLUME_DOWN = "\uE903";
 const String ICON_AUDIOTRACK = "\uE904";
 const String ICON_LIBRARY_MUSIC = "\uE905";
 const String ICON_FAVORITE = "\uE906";
 const String ICON_FAVORITE_OUTLINE = "\uE907";
 const String ICON_SHUFFLE_ON = "\uE908";
 const String ICON_SHUFFLE = "\uE909";
 const String ICON_SKIP_PREVIOUS = "\uE90A";
 const String ICON_SKIP_NEXT = "\uE90B";
 const String ICON_PLAY_ARROW = "\uE90C";
 const String ICON_PAUSE = "\uE90D";
 const String ICON_WIFI = "\uE90E";
 const String ICON_SPOTIFY = "\uEA94";

TFT_eSPI tft = TFT_eSPI(135, 240);
TFT_eSprite img = TFT_eSprite(&tft);
TFT_eSprite ico = TFT_eSprite(&tft);

const int centerX = 120;
const int lineOne = 10;
const int lineTwo = lineOne + LINE_HEIGHT + 9;
const int lineThree = lineTwo + LINE_HEIGHT;
const int lineSpacing = 3;
const int textPadding = 10;
const int textWidth = 239 - textPadding * 2;
#define TFT_LIGHTBLACK       0x1082      /*  16,   16,  16 */

#define ADC_EN          14  //ADC_EN is the ADC detection enable port
#define ADC_PIN         34
#define ROTARY_ENCODER_A_PIN 12
#define ROTARY_ENCODER_B_PIN 13
#define ROTARY_ENCODER_BUTTON_PIN 15
ESPRotary knob(ROTARY_ENCODER_A_PIN, ROTARY_ENCODER_B_PIN, 4);
OneButton button(ROTARY_ENCODER_BUTTON_PIN, true, true);

#include "genres.h"
#include "settings.h"
#include "spotify.h"

#define startsWith(STR, SEARCH) (strncmp(STR, SEARCH, strlen(SEARCH)) == 0)

enum EventsLogTypes { log_line, log_raw };

AsyncWebServer server(80);
AsyncEventSource events("/events");

int vref = 1100;
float batteryVoltage = 0.0;
String nodeName = "knobby";
RTC_DATA_ATTR unsigned int bootCount = 0;
RTC_DATA_ATTR time_t bootSeconds = 0;
bool sendLogEvents = false;
RTC_DATA_ATTR uint16_t genreIndex = 0;
RTC_DATA_ATTR time_t lastSleepSeconds = 0;
time_t secondsAsleep = 0;
unsigned long clickEffectMillis = 30;
unsigned long clickEffectEndMillis = 0;
unsigned long inactivityMillis = 60000;
const unsigned int batteryReportIntervalMillis = 30000;
unsigned long lastBatteryReportMillis = 0;
unsigned long lastBatteryUpdateMillis = 0;
unsigned long lastInputMillis = 1;
unsigned long lastDisplayMillis = 0;
unsigned long lastReconnectAttemptMillis = 0;
unsigned long randomizingMenuEndMillis = 0;
unsigned long randomizingMenuTicks = 0;
bool inputLocked = false;
bool randomizingMenuAutoplay = false;
bool displayInvalidated = true;
bool displayInvalidatedPartial = false;
char statusMessage[24] = "";
unsigned long statusMessageUntilMillis = 0;

enum MenuModes {
  RootMenu = -1,
  UserList = 0,
  DeviceList = 1,
  BookmarksList = 2,
  CountryList = 3,
  AlphabeticList = 4,
  AlphabeticSuffixList = 5,
  PopularityList = 6,
  SimilarList = 7,
  ToggleBookmarkItem = 8,
  VolumeControl = 9,
  NowPlaying = 10
};
RTC_DATA_ATTR MenuModes menuMode = AlphabeticList;
MenuModes lastMenuMode = AlphabeticList;
MenuModes lastPlaylistMenuMode = AlphabeticList;
MenuModes lastFullGenreMenuMode = AlphabeticList;
uint16_t lastMenuIndex = 0;
const char *rootMenuItems[] = {"users",      "devices", "bookmarks",        "countries", "name",   "name ending",
                               "popularity", "similar", "add/del bookmark", "volume", "now playing"};

enum NowPlayingButtons {
  ShuffleButton = 0,
  BackButton = 1,
  PlayPauseButton = 2,
  NextButton = 3
};

typedef struct {
  char playlistId[SPOTIFY_ID_SIZE + 1];
  char name[18];
} SimilarItem_t;
std::vector<SimilarItem_t> similarMenuItems;
int playingGenreIndex = -1;
int similarMenuGenreIndex = -1;

#define MAX_BOOKMARKS 1024
uint16_t bookmarksCount = 0;
const char *bookmarkedGenres[MAX_BOOKMARKS];

RTC_DATA_ATTR uint16_t menuSize = GENRE_COUNT;
RTC_DATA_ATTR uint16_t menuIndex = 0;
int lastKnobPosition = 0;
float lastKnobSpeed = 0.0;
const unsigned long extraLongPressMillis = 1250;
unsigned long longPressStartedMillis = 0;
bool knobRotatedWhileLongPressed = false;
int rootMenuSimilarIndex = -1;
int rootMenuToggleBookmarkIndex = -1;
int rootMenuVolumeControlIndex = -1;
int rootMenuNowPlayingIndex = -1;

TaskHandle_t backgroundApiTask;

void drawCenteredText(const char *text, uint16_t maxWidth, uint16_t maxLines = 1) {
  const uint16_t lineHeight = img.gFont.yAdvance + lineSpacing;
  // const uint16_t spriteHeight = img.gFont.yAdvance * maxLines + lineSpacing * (maxLines - 1);
  const uint16_t centerX = round(maxWidth / 2.0);
  const uint16_t len = strlen(text);

  uint16_t lineNumber = 0;
  uint16_t pos = 0;
  int16_t totalWidth = 0;
  uint16_t index = 0;
  uint16_t preferredBreakpoint = 0;
  uint16_t widthAtBreakpoint = 0;
  bool breakpointOnSpace = false;
  uint16_t lastDrawnPos = 0;

  img.createSprite(maxWidth, img.gFont.yAdvance);

  while (pos < len) {
    uint16_t lastPos = pos;
    uint16_t unicode = img.decodeUTF8((uint8_t *)text, &pos, len - pos);
    int16_t width = 0;

    if (img.getUnicodeIndex(unicode, &index)) {
      if (pos == 0) width = -img.gdX[index];
      if (pos == len - 1) {
        width = (img.gWidth[index] + img.gdX[index]);
      } else {
        width = img.gxAdvance[index];
      }
    } else {
      width = img.gFont.spaceWidth + 1;
    }
    totalWidth += width;

    // Always try to break on a space or dash
    if (unicode == ' ') {
      preferredBreakpoint = pos;
      widthAtBreakpoint = totalWidth - width;
      breakpointOnSpace = true;
    } else if (unicode == '-') {
      preferredBreakpoint = pos;
      widthAtBreakpoint = totalWidth;
      breakpointOnSpace = false;
    }

    if (totalWidth >= maxWidth - width) {
      if (preferredBreakpoint == 0) {
        preferredBreakpoint = lastPos;
        widthAtBreakpoint = totalWidth;
        breakpointOnSpace = false;
      }
      uint16_t lineLength = preferredBreakpoint - lastDrawnPos;
      uint16_t lineWidth = widthAtBreakpoint;

      char line[lineLength + 1] = {0};
      strncpy(line, &text[lastDrawnPos], lineLength);

      img.setCursor(centerX - round(lineWidth / 2.0), 0);
      img.printToSprite(line, lineLength);
      img.pushSprite(tft.getCursorX(), tft.getCursorY());
      tft.setCursor(tft.getCursorX(), tft.getCursorY() + lineHeight);
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

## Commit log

2019-08-19 Implement devices menu
2019-08-20 Persist device ID
2019-08-27 WIP user switching
2019-09-18 Finished dynamic users and devices
2020-03-31 Add case
    [knobby2-case.stl, knobby2-knob.stl, knobby2-lid.stl]
2020-04-25 Add playing track, splash screen
2020-04-25 Transfer playback between devices
2020-04-25 Show track duration
2020-06-06 Add battery voltage
2020-06-06 Use vectors for users and devices
2020-06-07 Fix extra line + currently playing after sleep
    [everynoise.ino]
2020-07-04 Add battery voltage reporting
2020-07-08 Use esp-idf for better power management
    [partitions.csv]
2020-08-05 Remove title screen, fix randomize on start
    [main.cpp]
2020-08-06 Replace bookmarks menu with playlists
    [main.cpp, main.h]
2020-08-14 Hide voltage unless low
2020-08-23 Fix button redraw
2020-08-23 Add more characters to font
    [partitions.csv]
2020-08-23 Remove battery voltage reporting
2020-08-24 Fix initial setup, check CA cert
    [main.cpp, main.h]
2020-08-24 Add case and knob STLs and photos
    [case-body.stl, case-lid.stl, knob.stl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]
2020-08-25 Go back to 240mhz to fix scroll performance
    [main.cpp, main.h]
2020-09-08 Fix menu skipping after sleep
    [main.cpp, main.h]
2020-09-09 Fix adding new user
    [main.cpp]
2020-09-25 Improve menus, use interrupts, save power
2020-10-21 Add STEP files
    [case.step, knob.step]
2020-11-07 Fix leftover genre on wake
    [main.cpp]
2020-11-07 Only get+save token when actually switching users
2020-11-07 Only write data when actually changing devices
2020-11-07 Only show progress bar when “waiting”
2020-11-08 Thicken case slightly for stiffness and symmetry
    [case-body.stl, case-lid.stl]
2020-11-18 Add ArduinoOTA + web firmware updating
2020-11-19 Fix reconnected status message on startup
    [main.cpp]
2020-11-21 Fix "- none -" when skipping prev/next in album
    [main.cpp]
2020-11-21 Allow more time to skip to previous track
    [main.cpp]
2020-11-22 Add empty state for devices menu
2020-11-25 Fix hold for random on start
    [main.cpp]
2020-12-21 Add battery indicator and low battery shutdown
2020-12-21 Improve button state handling
2020-12-25 Fix watchdog timer during wifi config portal
    [main.cpp]
2020-12-26 Switch to one genres menu, double click to sort
2020-12-27 Don’t randomize transient menus from sleep
2020-12-28 Fix conditions for double click
    [main.cpp]
2021-01-09 Retry then prompt if selected device is offline
2021-01-26 Fix watchdog triggered by continuous input
    [main.cpp, main.h]
2021-02-03 Switch to PKCE auth flow
    Closes #2
2021-02-03 Fix transferring playback between devices
    [main.cpp]
2021-02-04 Add T-Watch encoder version support
2021-02-05 Support longer artist and track names
2021-02-09 Improve low battery shutdown
2021-02-09 Flash message before reset
    [main.cpp]
2021-02-13 Apply ADC fix from TTGO example
    https://github.com/Xinyuan-LilyGO/TTGO-T-Display/commit/5ccb17d15b5ad2308fd274e9efecb7c98058d384
    [knobby.h]
2021-02-27 Tweak battery thresholds
2021-04-02 Fix low battery check before updating
    [main.cpp]
2021-04-21 Fix heap overflow with too many playlists
    [main.cpp]
2021-04-30 Add track likes, redesign now playing
    [main.cpp, main.h]
2021-05-05 Update Spotify root certificate, add error message
    [main.cpp]
2021-05-12 Add auth scope for track favoriting
2021-05-12 Rework battery management
2021-05-12 Track clicked menu item separately from selected
2021-05-15 Fix status message not clearing on now playing
    [main.cpp]
2021-05-20 Use regular battery percentage thresholds
2021-05-20 Reset shuffle + repeat state after long sleep
    [main.cpp]
2021-09-12 Fix incorrect pin on twatch
2021-10-20 Update ArduinoJson
2021-10-31 Fix display invalidation after long status message
    [main.cpp]
2022-01-20 Bump ArduinoJson
2022-01-28 Fix crash when playing local tracks having no id
    [main.cpp]
2022-01-30 Fix git version in serial output
    [knobby.h]
2022-03-07 Try to fix rare boot with backlight off bug
    [main.cpp]
2022-03-30 Tweak charging voltage threshold
2022-04-02 Update wiring diagram
2022-04-07 Set ARDUINO_BOARD
2022-04-11 Fix improv serial timeout after flashing
    [ImprovSerial.cpp, main.cpp]
2022-04-28 Add track seeking
2022-04-29 Try to fix rare boot with blank screen bug
    [main.cpp]
2022-04-29 Fix repeated checks for liked track
    [main.cpp]
2022-04-30 Fix hostname in improv response
    [main.cpp]
2022-05-08 Use ESP-IDF 4.4.1 and Arduino 2.0.3
2022-05-13 Allow longer Spotify device id
    Some Amazon Echo devices can have longer ids apparently.
2022-05-14 Fix redraw after status message
    [main.cpp]
2022-05-14 Return to last selected button
2022-05-14 Retry playback after selecting missing device
    [main.cpp]
2022-06-02 Avoid update when other actions are queued
    [main.cpp]
2022-06-11 Update arduino-esp32
2022-06-26 Make encoder pulse count configurable
2022-07-09 Update arduino submodule
2022-07-24 Add backoff after empty currently playing response
2022-07-24 Fix rotary encoder link
2022-10-04 Reset menu index when track changes
    [main.cpp]
2022-10-04 Reset knob velocity if direction changes
    [main.cpp, main.h]
2022-10-12 Fix status message clearing
    [main.cpp, main.h]
2022-11-05 Use esp-idf 4.4.2 / arduino 2.0.5
    arduino
2022-11-05 Fix wifi connect timeout
    [main.cpp]
2022-11-05 Update header, workaround slow serial bug
    [knobby.h]
2022-11-05 Fix pause on long device id
    [main.cpp]
2022-11-07 Fix log message for empty error response
    [main.cpp]
2022-11-07 Use track relinking
2022-11-07 Prevent API actions before auth
    [main.cpp]
2022-11-13 Fix random play context
    [main.cpp]
2022-12-17 Revert to static hostname
    [ImprovSerial.cpp, knobby.h, main.cpp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]
2022-12-18 Fix saving wifi network
    [knobby.h, main.cpp, main.h]
2022-12-18 Fix selected menu item
    [main.cpp]
2023-01-12 Fix default firmware url
    [main.cpp, main.h]
2023-01-15 Improve string handling, fix lengths
    [main.cpp, main.h]
2023-02-06 Fix explore menu loading
    [main.cpp]
2023-02-06 Avoid API call during firmware update
    [main.cpp]
2023-02-26 Update esp-idf + arduino
2023-04-24 Fix last genre name on boot
    [main.cpp]
2023-04-24 Update to Arduino 2.0.8
2023-07-20 Update to Arduino 2.0.10
2023-07-20 Fix web hardware config
    [main.cpp]
2024-01-02 Update esp-idf + arduino + dependencies
2024-01-02 Don't interrupt seeking
2024-01-28 Fix serial + web setup for S3
    [main.cpp, main.h]
2024-01-28 Fix backlight + battery for S3
    [knobby.h, main.cpp]
2024-02-15 Fix "can't connect" errors with new certificates
    [main.cpp, main.h]
2024-02-24 Fix 'Liked Songs,' cache Spotify User ID
    [main.cpp, main.h]
2024-02-24 Fix album art when changing tracks
    [main.cpp]
2024-03-03 Fix reversed auth flag in improv serial
    [ImprovSerial.cpp]
2024-03-03 Skip duplicate wifi SSIDs
    [ImprovSerial.cpp]
2024-03-03 Add note to wake device
2024-06-20 Fix playlists menu loading
    [main.cpp, main.h]
2024-11-25 Fix http status code success conditions
    [main.cpp]
2025-12-14 Allow longer spotifyAccessToken
    My first Spotify account seems to get shorter tokens, but a newer account gets a 312 byte token.
    [main.h]
2025-12-14 Save after flipping display from settings menu
    [main.cpp]
2025-12-14 Avoid empty firmware URL
    [main.cpp]
